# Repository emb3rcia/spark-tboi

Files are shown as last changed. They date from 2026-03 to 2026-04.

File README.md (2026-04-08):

# spark-tboi
# Navigation
- [About project](#about-project)
  - [Motivation for the project](#motivation-for-the-project)
  - [Humorous additions](#humorous-additions)
  - [Pin tables](#pin-tables)
  - [Development tools](#development-tools)
  - [Features](#features)
- [Images](#images)
- [License](#license)

# About project

spark-tboi is small-footprint keyboard/macropad with autoclicking capabilities and hot-swappable switches for The Binding of Isaac: Repentance+

## Motivation for the project

spark-debug was created to reduce strain on arms that happens when spam-clicking arrow keys with items such as Spirit Sword or Chocolate Milk

## Humorous additions

I added humorous silkscreen text as this project lacks personality without them in my opinion.

## Pin tables

Pin tables on PCB's silkscreen are named based on IC pins, not on desired connection on it. This means that TX UART pin should be plugged to RX of debugged device and vice versa.

## Usage

spark-tboi can run either only with firmware only or with integration with TBoI via mod that will be made after building the device.

## Directory overview

- 3D file of PCB and case files are available in `/3D`
- KiCad project files are available in `/KiCad Project Files`
- Gerber files are available in `/Gerbers`
- Firmware files are available in `/Firmware`

## Development tools

- KiCad for EDA work
- STM32CubeMX and CLion for firmware
- Fusion Educational Edition for CAD work

## Features

- Small footprint
- Autoclicking capabilities for specific items
- OLED screen

# Images

Schematic

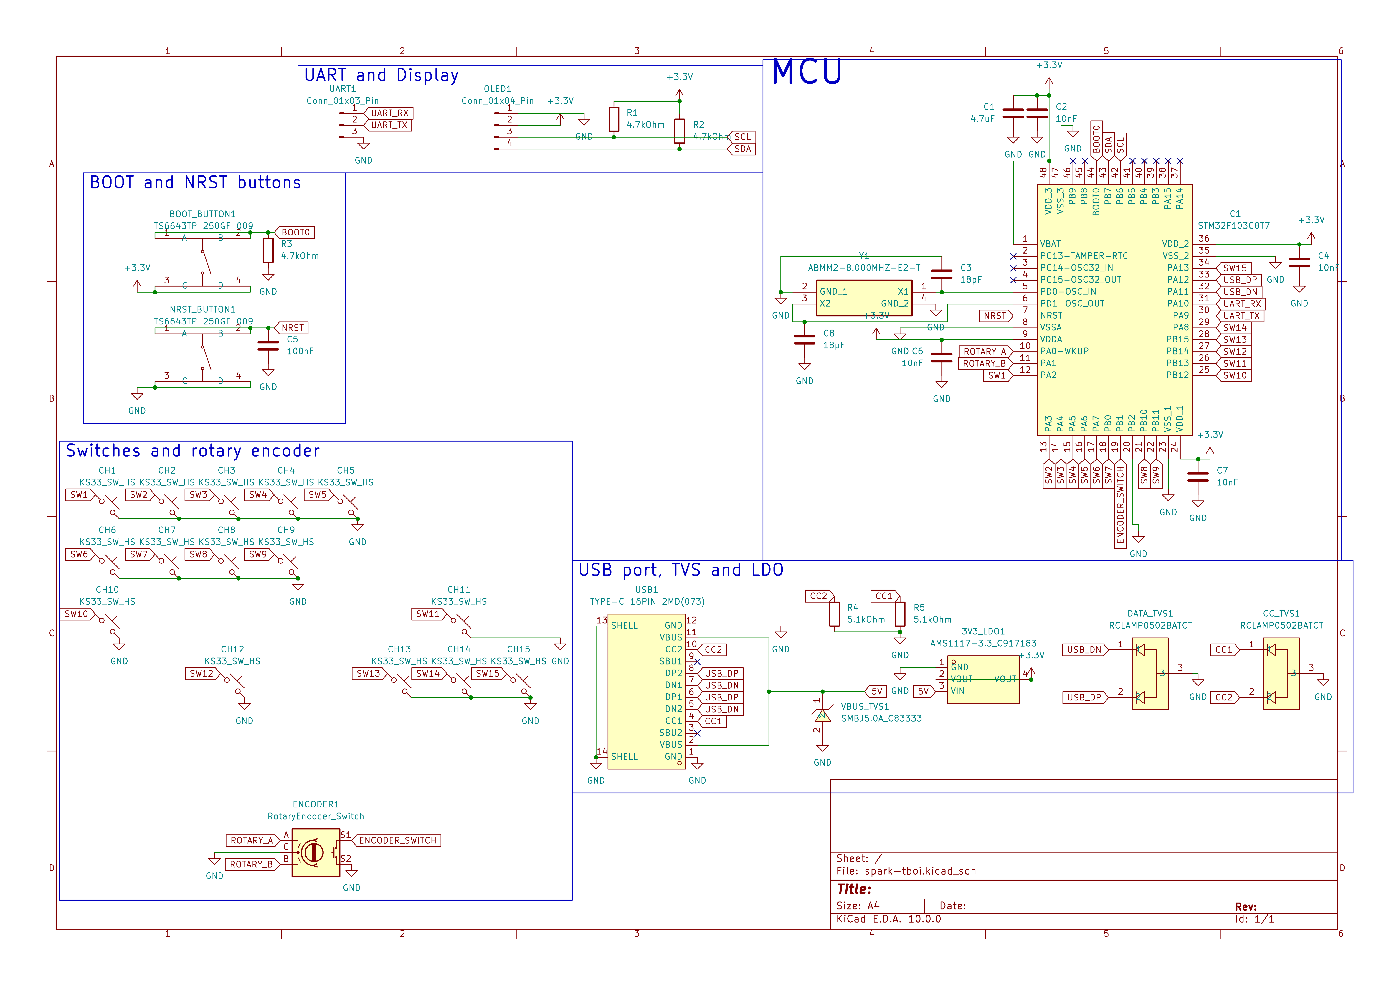
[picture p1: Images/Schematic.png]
schematic


3D viewer top side

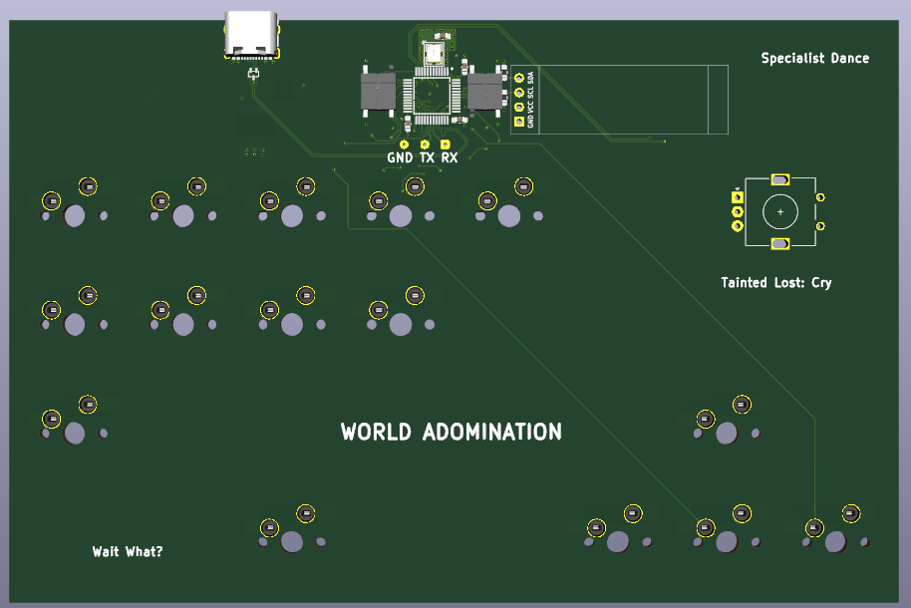
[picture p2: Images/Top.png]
3d top side


3D viewer bottom side

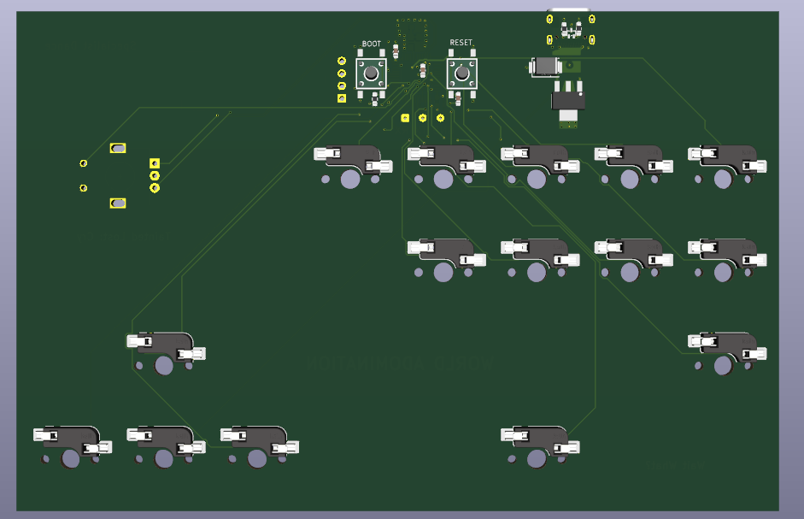
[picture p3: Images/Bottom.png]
3d bottom side


Case assembled

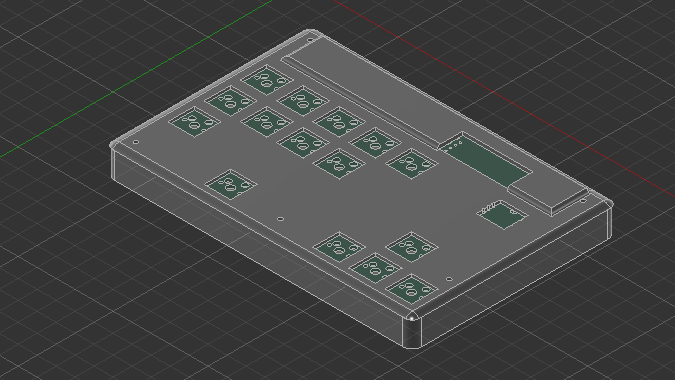
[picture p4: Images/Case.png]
case assembled


Top plate

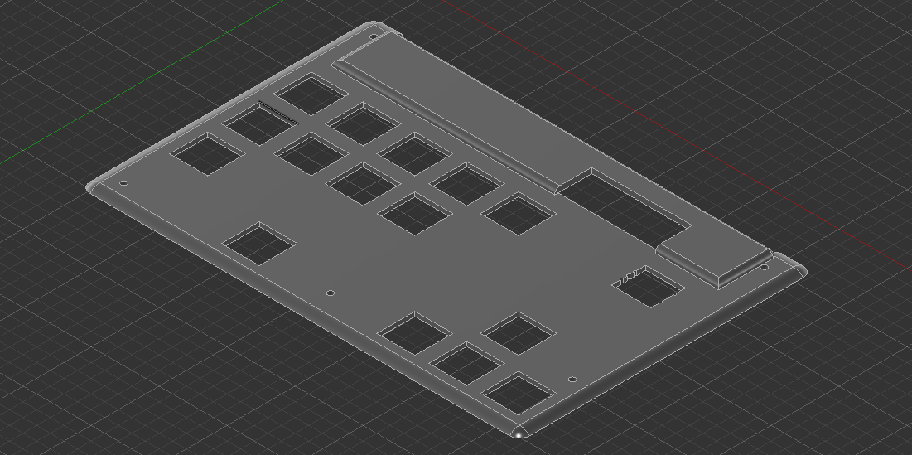
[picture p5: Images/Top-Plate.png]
top plate


Bottom case

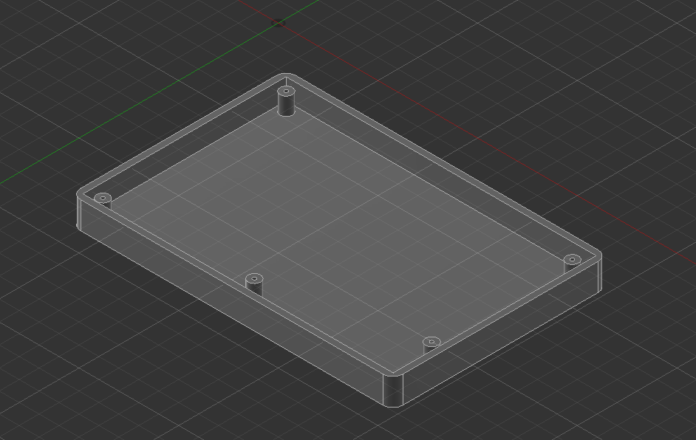
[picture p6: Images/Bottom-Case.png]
bottom case


# License

## PCB / Schematic License

All files in `/PCB`, `/Schematic` and `/Gerbers` folders and their subsequent subfolders are licensed under the CERN Open Hardware License v2 (Weakly Reciprocal).

See `/Licenses/CERN-OHL.txt` for full terms.

## 3D files, images and documentation License

All files in `/3D`, `/Images` folders and their subsequent subfolders are licensed under the CC-BY 4.0 License.

See `/Licenses/CC-BY-4.0.txt` for full terms

## Software License

All files in `/Firmware` folder and their subsequent subfolders are licensed under the Apache 2.0 License.

See `/Licenses/Apache-2.0.txt` for full terms.

# BOM

|Name |Purpose |Quantity|Total Cost (USD)|Link |Distributor|
|---|---|---|---|---|---|
|GRM1555C1H180JA01D |Capacitors for crystal |2 |0.22 |https://www.tme.eu/pl/details/grm1555c1h180ja01d/kondensatory-mlcc-smd/murata/ |TME |
|0603B103K500CT |Decoupling capacitors for MCU |4 |0.27 |https://www.tme.eu/pl/en/details/0603b103k500ct/mlcc-smd-capacitors/walsin/ |TME |
|ABMM2-8.000MHZ-E2-T |8 MHz oscillator for USB FS |1 |1.03 |https://www.tme.eu/pl/en/details/abmm2-8.000mhz-e2/smd-quartz-generators/abracon/abmm2-8-000mhz-e2-t/|TME |
|Outemu Kailh CPG151101S11 |Hot-swap switches (i have them from other project) |15 |0.00 |https://pl.aliexpress.com/item/1005002637150446.html?gatewayAdapt=glo2pol |AliExpress |
|Switches and keycaps |Physical buttons (i have them from hackpad kit and other project)|15 |0.00 | |HackClub |
|FOJAN FRC0603J472 TS |Pull up/down resistors (i have them from other project) |3 |0.00 |https://www.lcsc.com/product-detail/C2907166.html |LCSC |
|Samsung Electro-Mechanics |10uf decoupling capacitor (i have them from other project) |1 |0.00 |https://www.lcsc.com/product-detail/C19702.html |LCSC |
|HRE CGA0603X7R104K500JT |100nf decoupling capacitors (i have them from other project) |2 |0.00 |https://www.lcsc.com/product-detail/C6119867.html |LCSC |
|Littelfuse SMBJ5.0A |TVS diode for vbus (i have it from different project) |1 |0.00 |https://www.lcsc.com/product-detail/C83333.html |LSCS |
|Alps EC11 |Rotary Encoder leftover from hackpad kit |1 |0.00 | |HackClub |
|SSD1306 |OLED 128x32 SSD1306 screen leftover from hackpad kit |1 |0.00 | |HackClub |
|SHOU HAN TYPE-C 16PIN 2MD(073)|USB-C Port (i have it from other project) |1 |0.00 |https://www.lcsc.com/product-detail/C2765186.html?s_z=n_C2765186 |LCSC |
|PCB |PCB |5 |32.50 |https://jlcpcb.com |JLCPCB |
|ST STM32F103C8T7 |MCU |1 |7.00 |https://www.tme.eu/pl/details/stm32f103c8t7/mikrokontrolery-st/stmicroelectronics/ |TME |

© 2026 emb3rcia

Hardware: CERN OHL v2
3D & Images: CC BY 4.0
Firmware: Apache 2.0

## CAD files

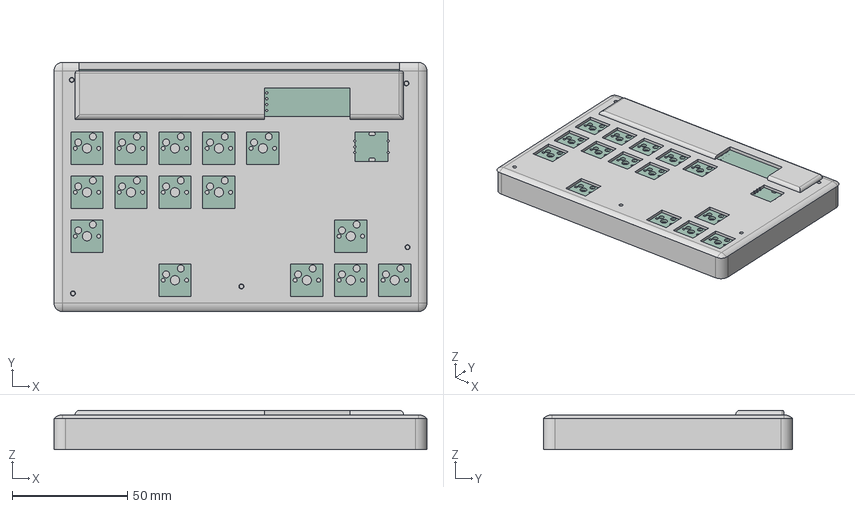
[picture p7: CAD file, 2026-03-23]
3D/STEP/case.step
161.6 x 108.0 x 17.1 mm
C_0603_1608Metric x 7
R_0603_1608Metric x 5
spark-tboi_PCB

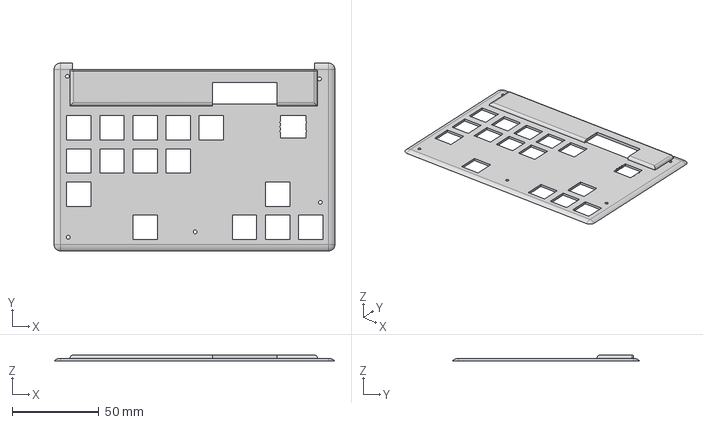
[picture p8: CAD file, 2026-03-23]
3D/STEP/top_plate.step
161.6 x 108.0 x 3.60 mm

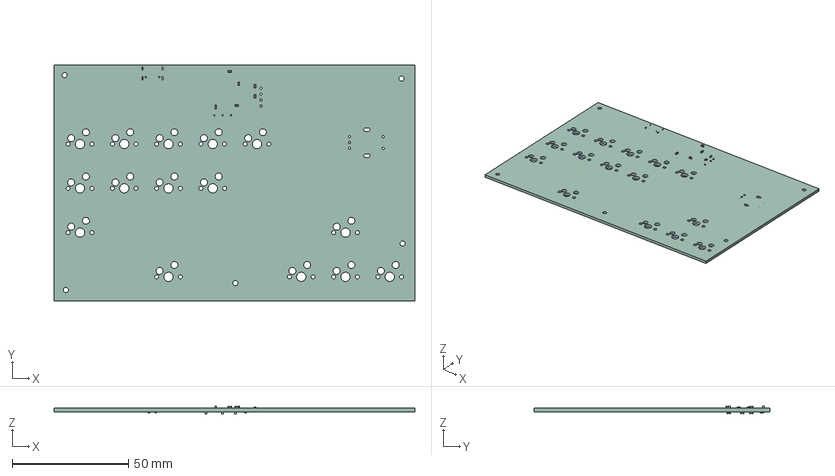
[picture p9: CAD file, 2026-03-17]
3D/STEP/pcb-kicad.step
155.4 x 101.8 x 3.28 mm
C_0603_1608Metric x 7
R_0603_1608Metric x 5
spark-tboi_PCB

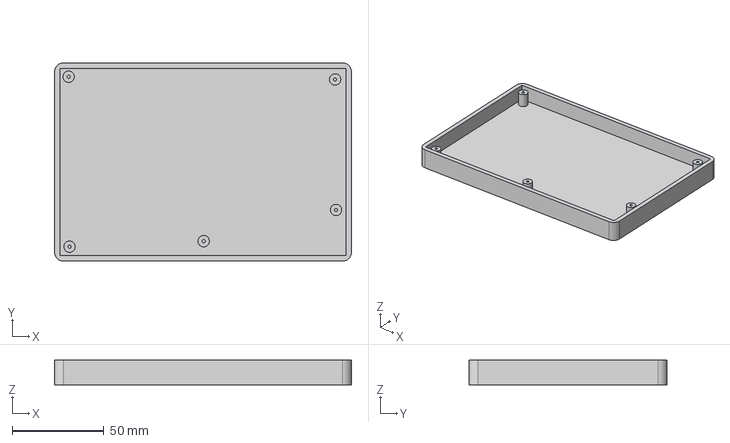
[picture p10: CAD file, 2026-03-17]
3D/STEP/bottom_case.step
161.6 x 108.0 x 13.5 mm

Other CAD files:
3D/STEP/pcb-fusion.step
3D/F3D/bottom_case.f3d
3D/F3D/pcb-fusion.f3d
3D/F3D/top_plate.f3d

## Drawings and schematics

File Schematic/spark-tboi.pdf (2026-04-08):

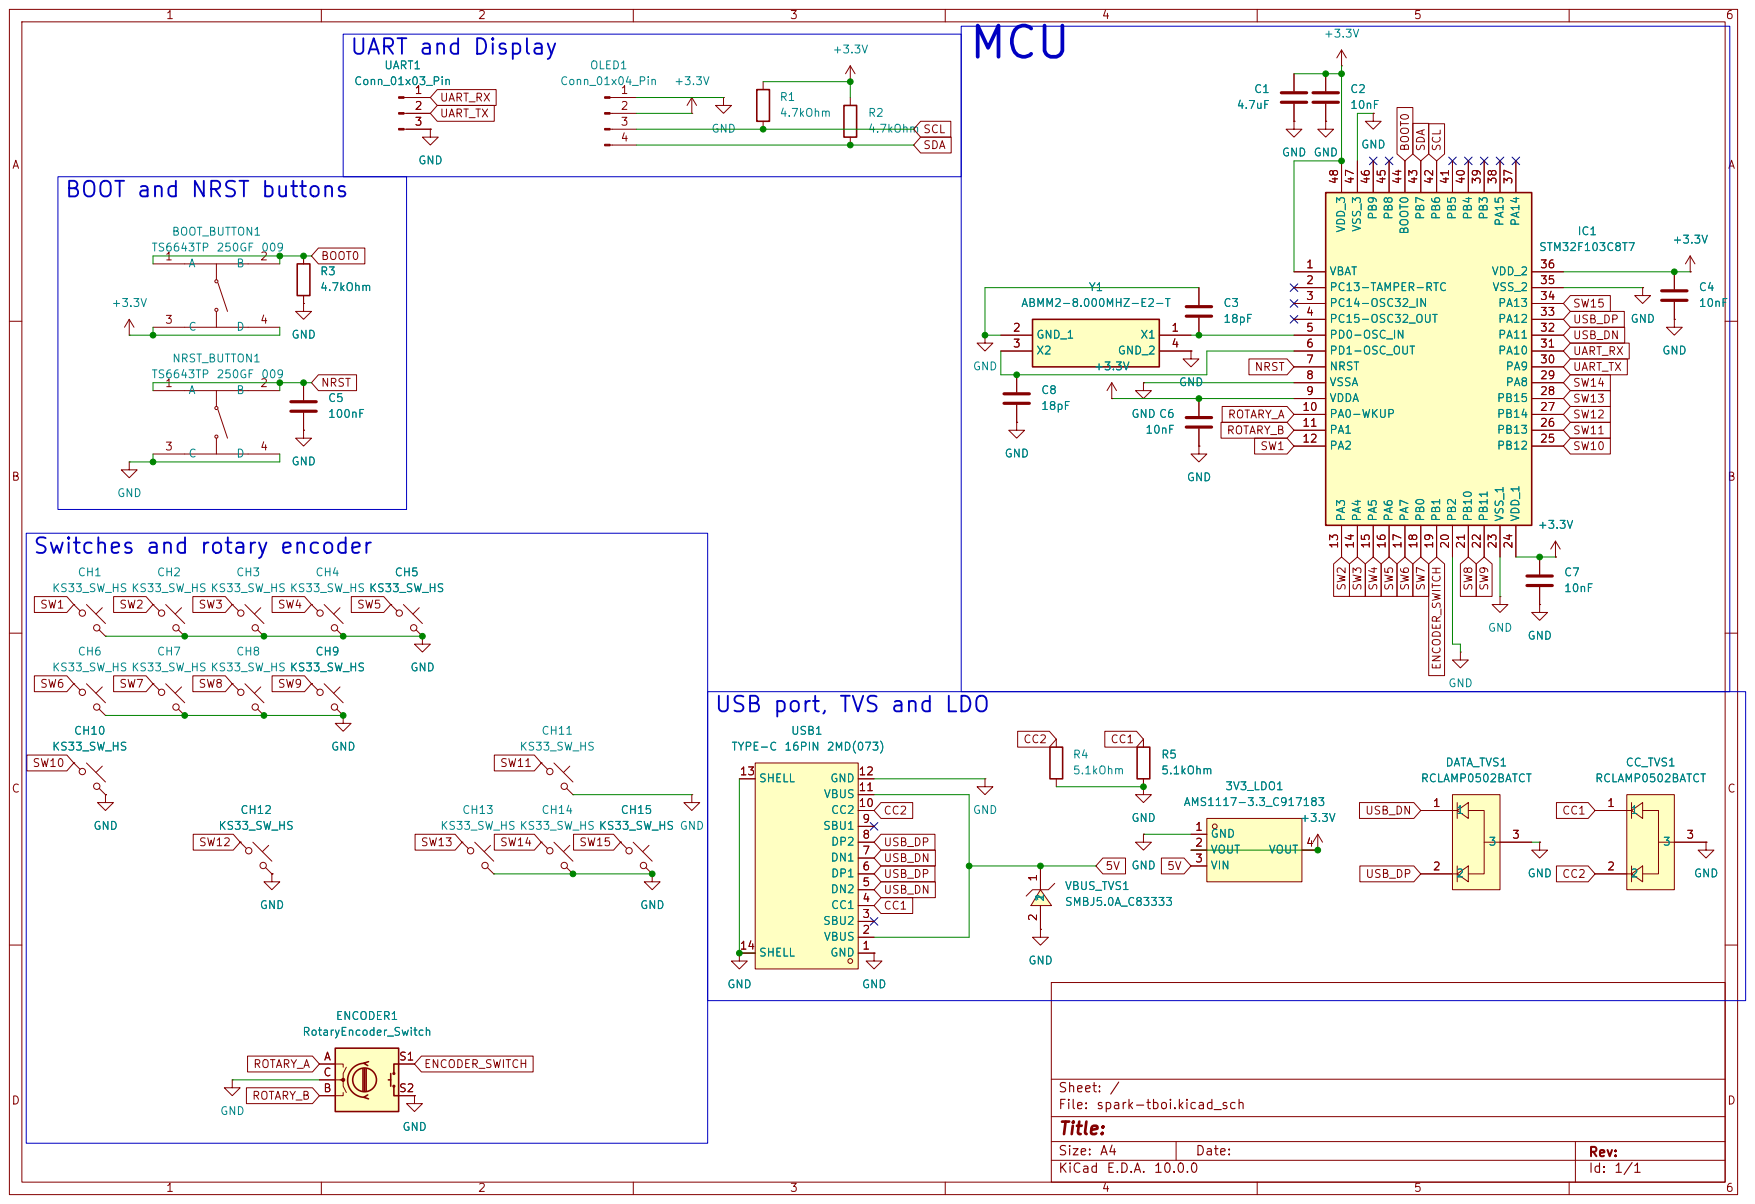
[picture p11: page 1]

UART and Display

BOOT and NRST buttons A 1 B 100nF R3

Switches and rotary encoder

USB port, TVS and LDO

Size: A4 | Rev:
KiCad E.D.A. 10.0.0 | Id: 1/1

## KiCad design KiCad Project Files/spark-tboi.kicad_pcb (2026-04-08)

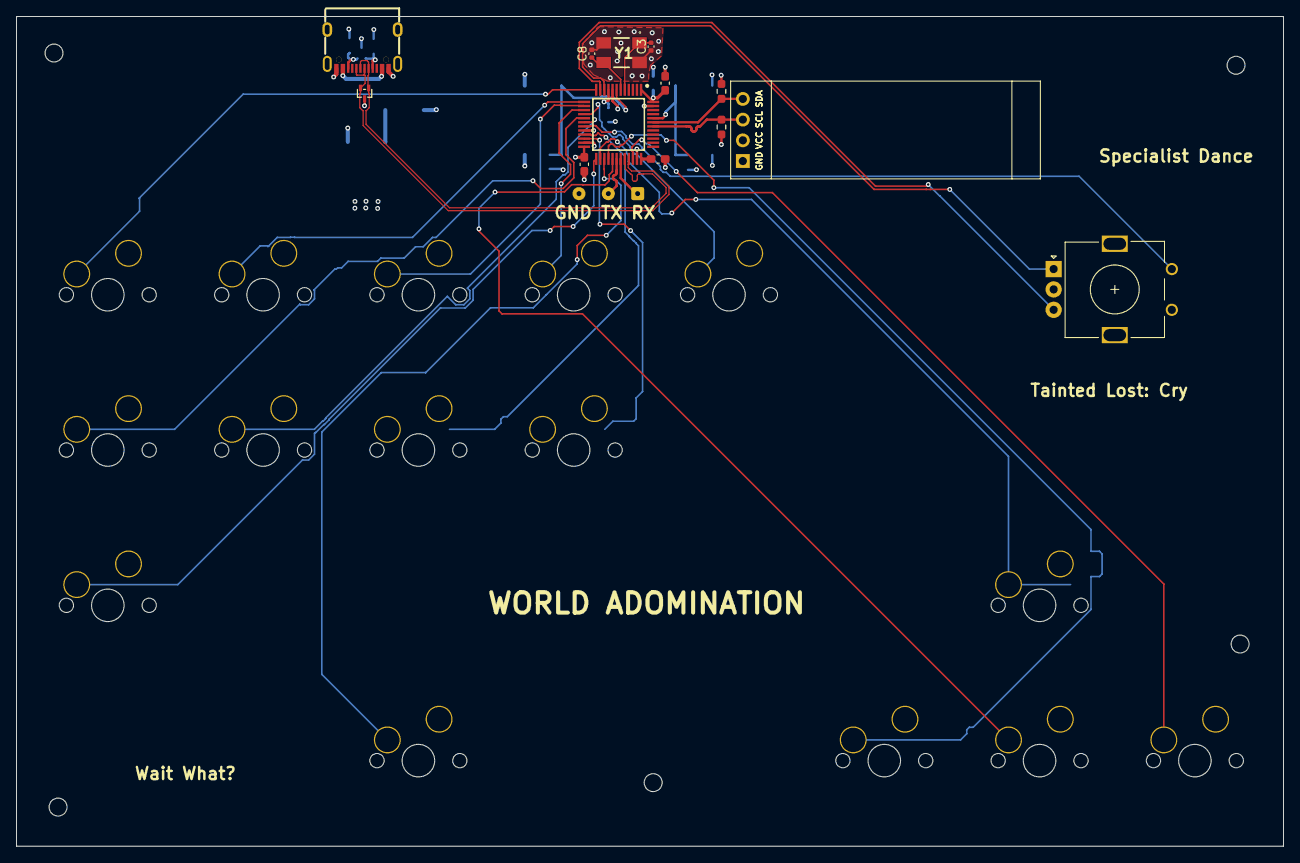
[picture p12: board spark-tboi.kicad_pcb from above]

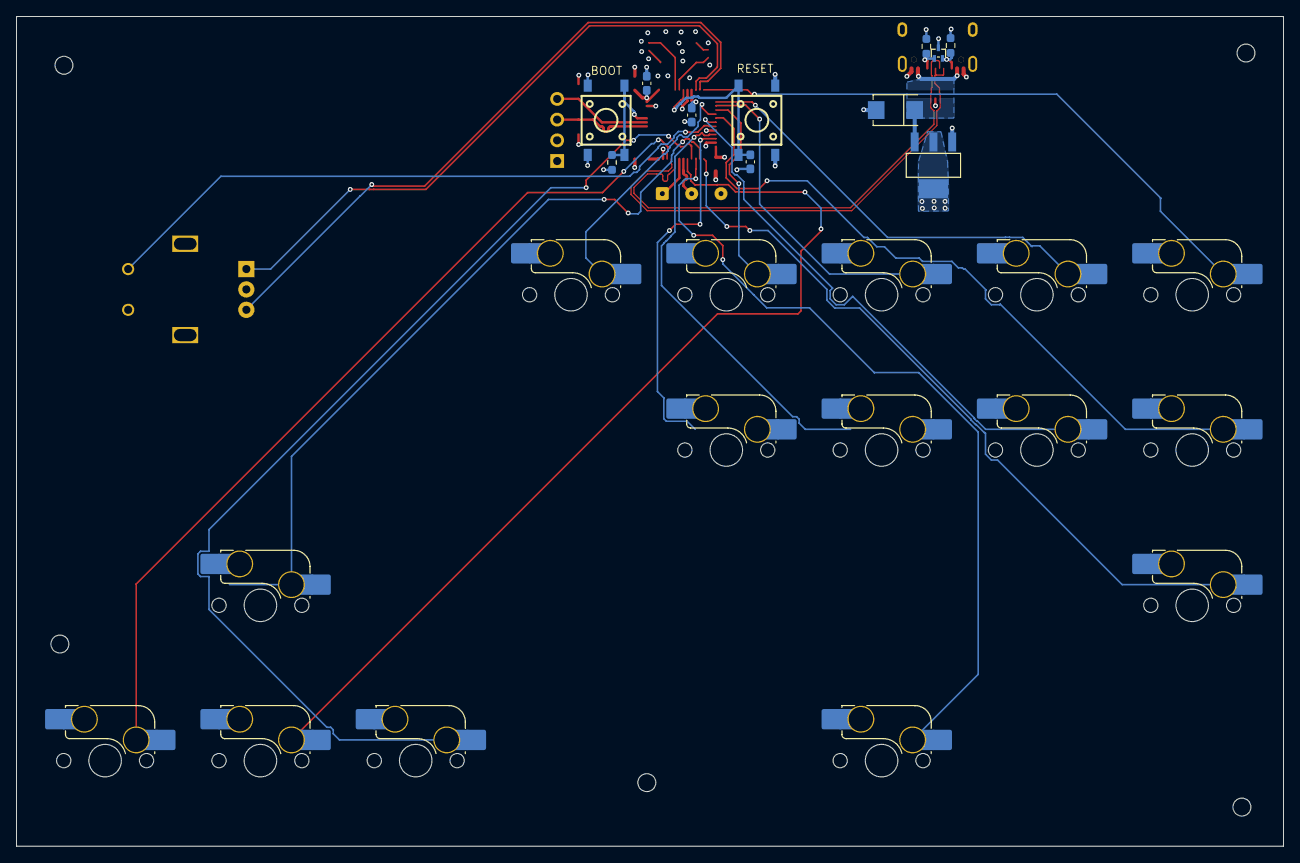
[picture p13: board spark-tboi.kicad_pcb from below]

Board: 4 copper layers, 155.4 x 101.8 mm, 40 parts (26 on the bottom side), 32 nets.

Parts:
3V3_LDO1: AMS1117-3.3_C917183; SOT-223-3_L6.7-W3.7-P2.30-LS7.0-BR
BOOT_BUTTON1: TS6643TP 250GF 009; SW-SMD_4P-L6.2-W6.0-P4.50-LS9.0
C1: 4.7uF; C_0603_1608Metric_Pad1.08x0.95mm_HandSolder
C2, C4, C6, C7: 10nF; C_0603_1608Metric_Pad1.08x0.95mm_HandSolder
C3, C8: 18pF; C_0402_1005Metric
C5: 100nF; C_0603_1608Metric_Pad1.08x0.95mm_HandSolder
CC_TVS1: RCLAMP0502BATCT; SC-75-3_L1.6-W0.8-P1.00-LS1.6-BR
CH1, CH2, CH3, CH4, CH5, CH6, CH7, CH8, CH9, CH10, CH11, CH12, CH13, CH14, CH15: KS33_SW_HS; SW_MX_HS_CPG151101S11_1u
DATA_TVS1: RCLAMP0502BATCT; SC-75-3_L1.6-W0.8-P1.00-LS1.6-BR
ENCODER1: RotaryEncoder_Switch; RotaryEncoder_Alps_EC11E_Vertical_H20mm
IC1: STM32F103C8T7; QFP50P900X900X160-48N
NRST_BUTTON1: TS6643TP 250GF 009; SW-SMD_4P-L6.2-W6.0-P4.50-LS9.0
OLED1: Conn_01x04_Pin; SSD1306-0.91-OLED-4pin-128x32
R1, R2, R3: 4.7kOhm; R_0603_1608Metric_Pad0.98x0.95mm_HandSolder
R4, R5: 5.1kOhm; R_0603_1608Metric_Pad0.98x0.95mm_HandSolder
UART1: Conn_01x03_Pin; SolderWire-0.1sqmm_1x03_P3.6mm_D0.4mm_OD1mm
USB1: TYPE-C 16PIN 2MD(073); USB-C-SMD_TYPE-C-6PIN-2MD-073
VBUS_TVS1: SMBJ5.0A_C83333; SMB_L4.6-W3.6-LS5.3-RD
Y1: ABMM2-8.000MHZ-E2-T; ABMM2

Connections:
5V: 3V3_LDO1.3 (VIN), USB1.2 (VBUS), USB1.11 (VBUS), VBUS_TVS1.1
+3.3V: 3V3_LDO1.2 (VOUT), 3V3_LDO1.4 (VOUT), BOOT_BUTTON1.3 (C), BOOT_BUTTON1.4 (D), C1.1, C2.1, C4.1, C6.1, C7.1, IC1.1 (VBAT), IC1.9 (VDDA), IC1.24 (VDD_1), IC1.36 (VDD_2), IC1.48 (VDD_3), OLED1.2, R1.1, R2.1
BOOT0: BOOT_BUTTON1.1 (A), BOOT_BUTTON1.2 (B), IC1.44 (BOOT0), R3.1
CC1: CC_TVS1.1, R5.1, USB1.4 (CC1)
CC2: CC_TVS1.2, R4.1, USB1.10 (CC2)
GND: 3V3_LDO1.1 (GND), C1.2, C2.2, C3.1, C4.2, C5.2, C6.2, C7.2, C8.2, CC_TVS1.3, CH1.2, CH2.2, CH3.2, CH4.2, CH5.2, CH6.2, CH7.2, CH8.2, CH9.2, CH10.2, CH11.2, CH12.2, CH13.2, CH14.2, CH15.2, DATA_TVS1.3, ENCODER1.C, IC1.8 (VSSA), IC1.20 (PB2), IC1.23 (VSS_1), IC1.35 (VSS_2), IC1.47 (VSS_3), NRST_BUTTON1.3 (C), NRST_BUTTON1.4 (D), OLED1.1, R3.2, R4.2, R5.2, UART1.3, USB1.1 (GND), USB1.12 (GND), USB1.13 (SHELL), USB1.14 (SHELL), VBUS_TVS1.2, Y1.2 (GND_1), Y1.4 (GND_2)
NRST: C5.1, IC1.7 (NRST), NRST_BUTTON1.1 (A), NRST_BUTTON1.2 (B)
unnamed: C3.2, IC1.5 (PD0-OSC_IN), Y1.1 (X1)
unnamed: C8.1, IC1.6 (PD1-OSC_OUT), Y1.3 (X2)
ROTARY_A: ENCODER1.A, IC1.10 (PA0-WKUP)
ROTARY_B: ENCODER1.B, IC1.11 (PA1)
SCL: IC1.42 (PB6), OLED1.3, R1.2
SDA: IC1.43 (PB7), OLED1.4, R2.2
SW1: CH1.1, IC1.12 (PA2)
SW2: CH2.1, IC1.13 (PA3)
SW3: CH3.1, IC1.14 (PA4)
SW4: CH4.1, IC1.15 (PA5)
SW5: CH5.1, IC1.16 (PA6)
SW6: CH6.1, IC1.17 (PA7)
SW7: CH7.1, IC1.18 (PB0)
SW8: CH8.1, IC1.21 (PB10)
SW9: CH9.1, IC1.22 (PB11)
SW10: CH10.1, IC1.25 (PB12)
SW11: CH11.1, IC1.26 (PB13)
SW12: CH12.1, IC1.27 (PB14)
SW13: CH13.1, IC1.28 (PB15)
SW14: CH14.1, IC1.29 (PA8)
SW15: CH15.1, IC1.34 (PA13)
UART_RX: IC1.31 (PA10), UART1.1
UART_TX: IC1.30 (PA9), UART1.2
USB_DN: DATA_TVS1.1, IC1.32 (PA11), USB1.5 (DN2), USB1.7 (DN1)
USB_DP: DATA_TVS1.2, IC1.33 (PA12), USB1.6 (DP1), USB1.8 (DP2)

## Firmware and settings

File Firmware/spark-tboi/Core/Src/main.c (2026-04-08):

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
/* Includes ------------------------------------------------------------------*/
#include "main.h"
#include "usb_device.h"

I2C_HandleTypeDef hi2c1;

TIM_HandleTypeDef htim2;

UART_HandleTypeDef huart1;

void SystemClock_Config(void);
static void MX_GPIO_Init(void);
static void MX_I2C1_Init(void);
static void MX_TIM2_Init(void);
static void MX_USART1_UART_Init(void);
/**
  * @brief  The application entry point.
  * @retval int
  */
int main(void)
{

  /* MCU Configuration--------------------------------------------------------*/

  /* Reset of all peripherals, Initializes the Flash interface and the Systick. */
  HAL_Init();

  /* Configure the system clock */
  SystemClock_Config();

  /* Initialize all configured peripherals */
  MX_GPIO_Init();
  MX_I2C1_Init();
  MX_TIM2_Init();
  MX_USART1_UART_Init();
  MX_USB_DEVICE_Init();
  /* USER CODE BEGIN 2 */
  ssd1306_Init();
  /* USER CODE END 2 */

  /* Infinite loop */
  /* USER CODE BEGIN WHILE */
  uint32_t last_loop_time = 0;
  const uint32_t loop_time_delay_ms = 1;
  while (1)
  {
    uint32_t now = HAL_GetTick();
    if (now - last_loop_time >= loop_time_delay_ms) {
      last_loop_time = now;

      handleEncoder();
      uint16_t descriptorReport = handleDescriptor();
      USBD_HID_SendReport(&hUsbDeviceFS, (uint8_t*)&descriptorReport, 2);
    }
    /* USER CODE END WHILE */

    /* USER CODE BEGIN 3 */
  }
  /* USER CODE END 3 */
}

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


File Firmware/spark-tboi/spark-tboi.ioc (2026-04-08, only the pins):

Mcu.UserName=STM32F103C8Tx
PA0-WKUP.GPIO_Label=ROTARY_A
PA0-WKUP.Signal=S_TIM2_CH1_ETR
PA1.GPIO_Label=ROTARY_B
PA1.Signal=S_TIM2_CH2
PA10.Signal=USART1_RX
PA11.Signal=USB_DM
PA12.Signal=USB_DP
PA13.GPIO_Label=SW15
PA13.Signal=GPIO_Input
PA2.GPIO_Label=SW1
PA2.Signal=GPIO_Input
PA3.GPIO_Label=SW2
PA3.Signal=GPIO_Input
PA4.GPIO_Label=SW3
PA4.Signal=GPIO_Input
PA5.GPIO_Label=SW4
PA5.Signal=GPIO_Input
PA6.GPIO_Label=SW5
PA6.Signal=GPIO_Input
PA7.GPIO_Label=SW6
PA7.Signal=GPIO_Input
PA8.GPIO_Label=SW14
PA8.Signal=GPIO_Input
PA9.Signal=USART1_TX
PB0.GPIO_Label=SW7
PB0.Signal=GPIO_Input
PB1.GPIO_Label=ENCODER_SWITCH
PB1.Signal=GPIO_Input
PB10.GPIO_Label=SW8
PB10.Signal=GPIO_Input
PB11.GPIO_Label=SW9
PB11.Signal=GPIO_Input
PB12.GPIO_Label=SW10
PB12.Signal=GPIO_Input
PB13.GPIO_Label=SW11
PB13.Signal=GPIO_Input
PB14.GPIO_Label=SW12
PB14.Signal=GPIO_Input
PB15.GPIO_Label=SW13
PB15.Signal=GPIO_Input
PB6.Signal=I2C1_SCL
PB7.Signal=I2C1_SDA
PD0-OSC_IN.Signal=RCC_OSC_IN
PD1-OSC_OUT.Signal=RCC_OSC_OUT

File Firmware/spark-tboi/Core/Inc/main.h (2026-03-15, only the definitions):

#define ROTARY_A_Pin GPIO_PIN_0
#define ROTARY_A_GPIO_Port GPIOA
#define ROTARY_B_Pin GPIO_PIN_1
#define ROTARY_B_GPIO_Port GPIOA
#define SW1_Pin GPIO_PIN_2
#define SW1_GPIO_Port GPIOA
#define SW2_Pin GPIO_PIN_3
#define SW2_GPIO_Port GPIOA
#define SW3_Pin GPIO_PIN_4
#define SW3_GPIO_Port GPIOA
#define SW4_Pin GPIO_PIN_5
#define SW4_GPIO_Port GPIOA
#define SW5_Pin GPIO_PIN_6
#define SW5_GPIO_Port GPIOA
#define SW6_Pin GPIO_PIN_7
#define SW6_GPIO_Port GPIOA
#define SW7_Pin GPIO_PIN_0
#define SW7_GPIO_Port GPIOB
#define ENCODER_SWITCH_Pin GPIO_PIN_1
#define ENCODER_SWITCH_GPIO_Port GPIOB
#define SW8_Pin GPIO_PIN_10
#define SW8_GPIO_Port GPIOB
#define SW9_Pin GPIO_PIN_11
#define SW9_GPIO_Port GPIOB
#define SW10_Pin GPIO_PIN_12
#define SW10_GPIO_Port GPIOB
#define SW11_Pin GPIO_PIN_13
#define SW11_GPIO_Port GPIOB
#define SW12_Pin GPIO_PIN_14
#define SW12_GPIO_Port GPIOB
#define SW13_Pin GPIO_PIN_15
#define SW13_GPIO_Port GPIOB
#define SW14_Pin GPIO_PIN_8
#define SW14_GPIO_Port GPIOA
#define SW15_Pin GPIO_PIN_13
#define SW15_GPIO_Port GPIOA

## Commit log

2026-03-16 added case
    [bottom_case.f3d, bottom_case.step, case.step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]
2026-03-16 added images of case
2026-03-16 fixed bom
    [BOM.csv]
2026-03-17 revised bom
    [BOM.csv, spark-tboi.kicad_sch]
2026-03-21 Update README with 3d case image // need to add encoder cutout next
2026-03-23 Added extrusion for encoder
    [case.step, top_plate.f3d, top_plate.step]
2026-04-08 Changed distributor to TME
    [BOM.csv, spark-tboi.kicad_pcb, spark-tboi.kicad_sch]

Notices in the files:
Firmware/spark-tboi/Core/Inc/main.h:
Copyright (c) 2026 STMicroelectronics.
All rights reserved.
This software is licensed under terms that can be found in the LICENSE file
